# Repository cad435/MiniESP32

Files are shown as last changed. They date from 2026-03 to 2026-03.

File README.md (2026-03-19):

# MiniESP32
A very small dev-board for the original ESP32 (XTENSA Dual-Core) with USB-C PD support.

---

## About
Since the ESP32-C3 was released I enjoyed the use of those ultra-small dev-boards.
Sadly there were no such dev-boards for the "original" ESP32 (XTENSA Dual-Core), so I created my own.

The board measures just **25x31mm** — only slightly bigger than the ESP32-WROOM module itself (19x26mm).

## Features
- **USB-C** connector
- **USB-PD** support via **CH224Q** PD controller
- **Switchable V+ output** — USB-PD voltage can be enabled/disabled via GPIO18
- All usable GPIOs broken out on 2.54mm headers
- 2x I2C, 2x UART, Touch, DAC, ADC
- Onboard LED on GPIO02, Boot button on GPIO00

## USB Power Delivery (CH224Q)
The V2.2 PD revision includes a **CH224Q** USB-PD sink controller.

- **Default output: 9V** — the CH224Q negotiates 9V on power-up
- The voltage can be changed to **5V** via software using the [CH224Q Arduino Library](https://github.com/cad435/CH224Q_Arduino)
- **V+ is switched** — GPIO18 controls a MOSFET that connects/disconnects the negotiated PD voltage to the V+ output pin. This allows you to turn the power output on and off programmatically
- **I2C connection** — the CH224Q is connected to I2C1 on GPIO21 (SDA) and GPIO22 (SCL)

## Pinout

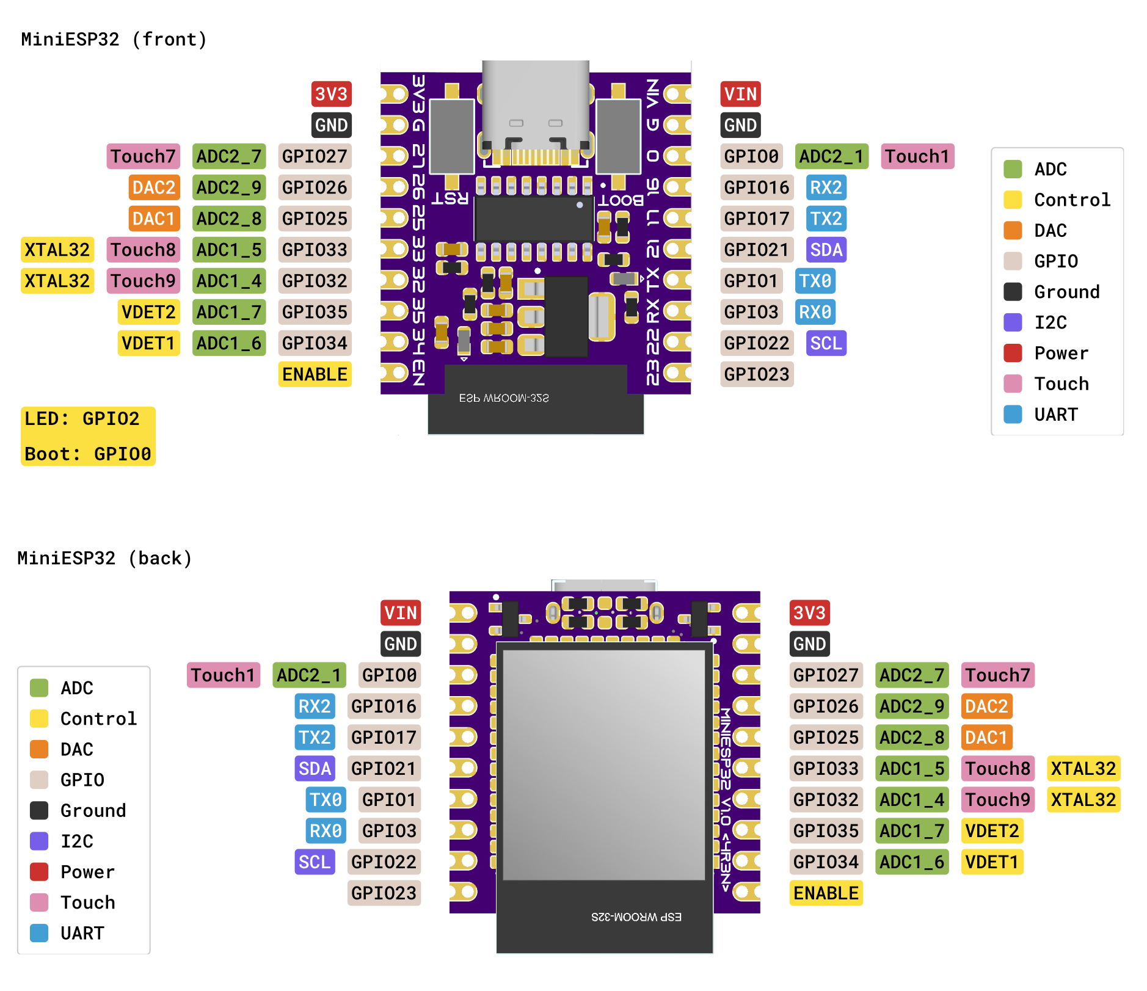
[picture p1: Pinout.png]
Pinout


## Manufacturing

Gerber and provided .xlsx files can be used to directly upload to JLCPCB (*.xlsx files for assembly service).

## Files
| File | Description |
|---|---|
| `MiniESP32_Gerber.zip` | Gerber files (panelized, ready for JLCPCB) |
| `MiniESP32_V2.2 PD-Schematic.PDF` | Schematic |
| `BOM-MiniESP32(V2.2 PD).pdf` | Bill of Materials |
| `MiniESP32_V2.2 PD_Assembly.PDF` | Assembly drawing |
| `MiniESP32_V2.2 PD_BoardSpec.PDF` | Board specifications |
| `JLC_PCBA_BOM-MiniESP32(V2.2 PD).xlsx` | BOM for JLCPCB assembly |
| `JLC_PCBA_CPL-MiniESP32(V2.2 PD).xlsx` | Component placement for JLCPCB assembly |
| `MiniESP32.step` | 3D model (STEP) |

## Photo

27b760d5-4e83-46a3-9fcc-3738d6150797

Note: the patched diode is now fixed and uploaded!

## License
Licensed under the [Open Source Hardware Association License](https://www.oshwa.org/definition/)

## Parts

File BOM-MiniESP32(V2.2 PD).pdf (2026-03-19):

Comment | Description | Value | Designator | Footprint | Quantity
CH224Q | USB PD and Other Fast Charging Protocol Sink Controller | | A2 | DFN40P200X75_HS-11N | 1
1uF/50V | Capacitor | 1uF/25V, 1uF/50V | C1, C2, C3, C5 | C0603 | 4
100nF | Capacitor | 100nF | C7, C8, C22, C24, C25 | C0402 | 5
10uF/50V | Capacitor | 10uF/50V | C10, C11 | C0805 | 2
10uF | Capacitor | 10uF | C23, C26, C27 | C0402 | 3
C2286 | SMD LED | | D1, D2 | 0603_LED | 2
C2290 | SMD LED | | D3 | 0603_LED | 1
15V/BZT52C15S | 15V/BZT52C15S | | D4 | SOD-323 | 1
B5819W SL | Diode | | D5 | SOD-123 | 1
ME3116 | 1A up to 40V Input Step-Down DC/DC Regulator | | IC1 | SOT23-6 | 1
C720477 | Tactile Switch | | J2, J3 | TS-1088-AR02016 | 2
USB 3.1 C Receptacle | USB 3.1 Type C Receptacle Horizontal THR WR-COM | | J4 | C165948 | 1
VLS252012HBX-100M-1 | VLS252012HBX-100M-1 | 10uH | L1 | 2.5x2mm | 1
ESP32S_Module | Esp-32S | | M1 | ESP32S | 1
WSD30L68DN33 | 20V P-Channel MOSFET | | Q1 | SON3x3 | 1
AO3400A | N-MOSFET SI2318CDS-T1-GE3 | | Q2, Q6, Q7 | SOT95P240X1.10-3N_SOT-23 | 3
1.5k | Resistor | 1.5k | R1, R2, R12 | 0402 | 3
6.8k | Resistor | 6.8k | R7 | R0603 | 1
100k | Resistor | 100k | R9, R16 | 0402 | 2
1M | Resistor | 1M | R10 | 0402 | 1
33k | Resistor | 33k | R11 | 0402 | 1
10k | Resistor | 10k | R13, R14, R17, R18, R25, R26, R27, R28 | 0402 | 8
1k | Resistor | 1k | R20 | 0402 | 1
CH340K | | | U1 | ESSOP100P600X180_E P-11N wo vias | 1

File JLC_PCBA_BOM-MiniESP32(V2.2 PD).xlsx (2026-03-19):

Comment | Description | Value | Designator | Footprint | Quantity | JLCPCB Part #
CH224Q | USB PD and Other Fast Charging Protocol Sink Controller |  | A2 | DFN40P200X75_HS-11N | 1 | C46061833
1uF/50V | Capacitor | 1uF/50V | C1 | C0603 | 1 | C15849
1uF/50V | Capacitor | 1uF/50V | C2 | C0603 | 1 | C15849
1uF/50V | Capacitor | 1uF/50V | C3 | C0603 | 1 | C15849
1uF/50V | Capacitor | 1uF/50V | C5 | C0603 | 1 | C15849
100nF | Capacitor | 100nF | C7, C8, C22, C24, C25 | C0402 | 5 | C307331
10uF/50V | Capacitor | 10uF/50V | C10, C11 | C0805 | 2 | C440198
10uF | Capacitor | 10uF | C23, C26, C27 | C0402 | 3 | C15525
C2286 | SMD LED |  | D1, D2 | 0603_LED | 2 | C2286
C2290 | SMD LED |  | D3 | 0603_LED | 1 | C2290
15V/BZT52C15S | Zener |  | D4 | SOD-323 | 1 | C19077448
ME3116 | 1A up to 40V Input Step-Down DC/DC Regulator |  | IC1 | SOT23-6 | 1 | C97643
C720477 | Tactile Switch |  | J2, J3 | TS-1088-AR02016 | 2 | C720477
USB 3.1 C Receptacle | USB 3.1 Type C Receptacle Horizontal THR WR-COM |  | J4 | C165948 | 1 | C165948
VLS252012HBX-100M-1 | VLS252012HBX-100M-1 | 10uH | L1 | 2.5x2mm | 1 | C88532
ESP32-WROOM | ESP32-WROOM | ESP32-WROOM | M1 | ESP32S | 1
WSD30L68DN33 | 20V P-Channel MOSFET |  | Q1 | SON3x3 | 1 | C5242075
AO3400A | N-MOSFET SI2318CDS-T1-GE3 |  | Q2, Q6, Q7 | SOT95P240X1.10-3N_SOT-23 | 3 | C20917
1.5k | Resistor | 1.5k | R1, R2, R12 | 0402 | 3 | C25867
6.8k | Resistor | 6.8k | R7 | R0603 | 1 | C23212
100k | Resistor | 100k | R9, R16 | 0402 | 2 | C25741
1M | Resistor | 1M | R10 | 0402 | 1 | C26083
33k | Resistor | 33k | R11 | 0402 | 1 | C25779
10k | Resistor | 10k | R13, R14, R17, R18, R25, R26, R27, R28 | 0402 | 8 | C25744
CH340K |  |  | U1 | ESSOP100P600X180_EP-11N wo vias | 1 | C18208922
B5819W SL | Diode |  | D5 | SOD-123 | 1

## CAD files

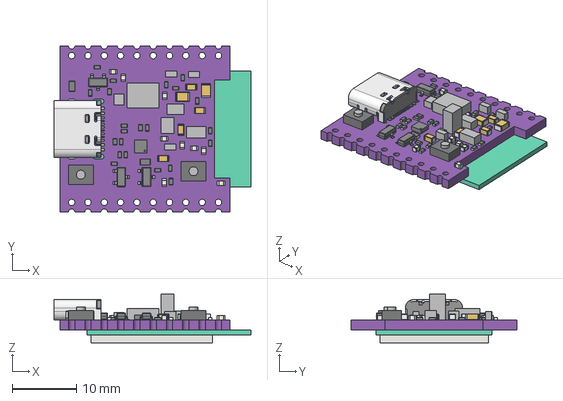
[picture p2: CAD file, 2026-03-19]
MiniESP32.step
30.7 x 25.9 x 7.56 mm

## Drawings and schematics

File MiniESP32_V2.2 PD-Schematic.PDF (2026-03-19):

10k | R4
10k | R5

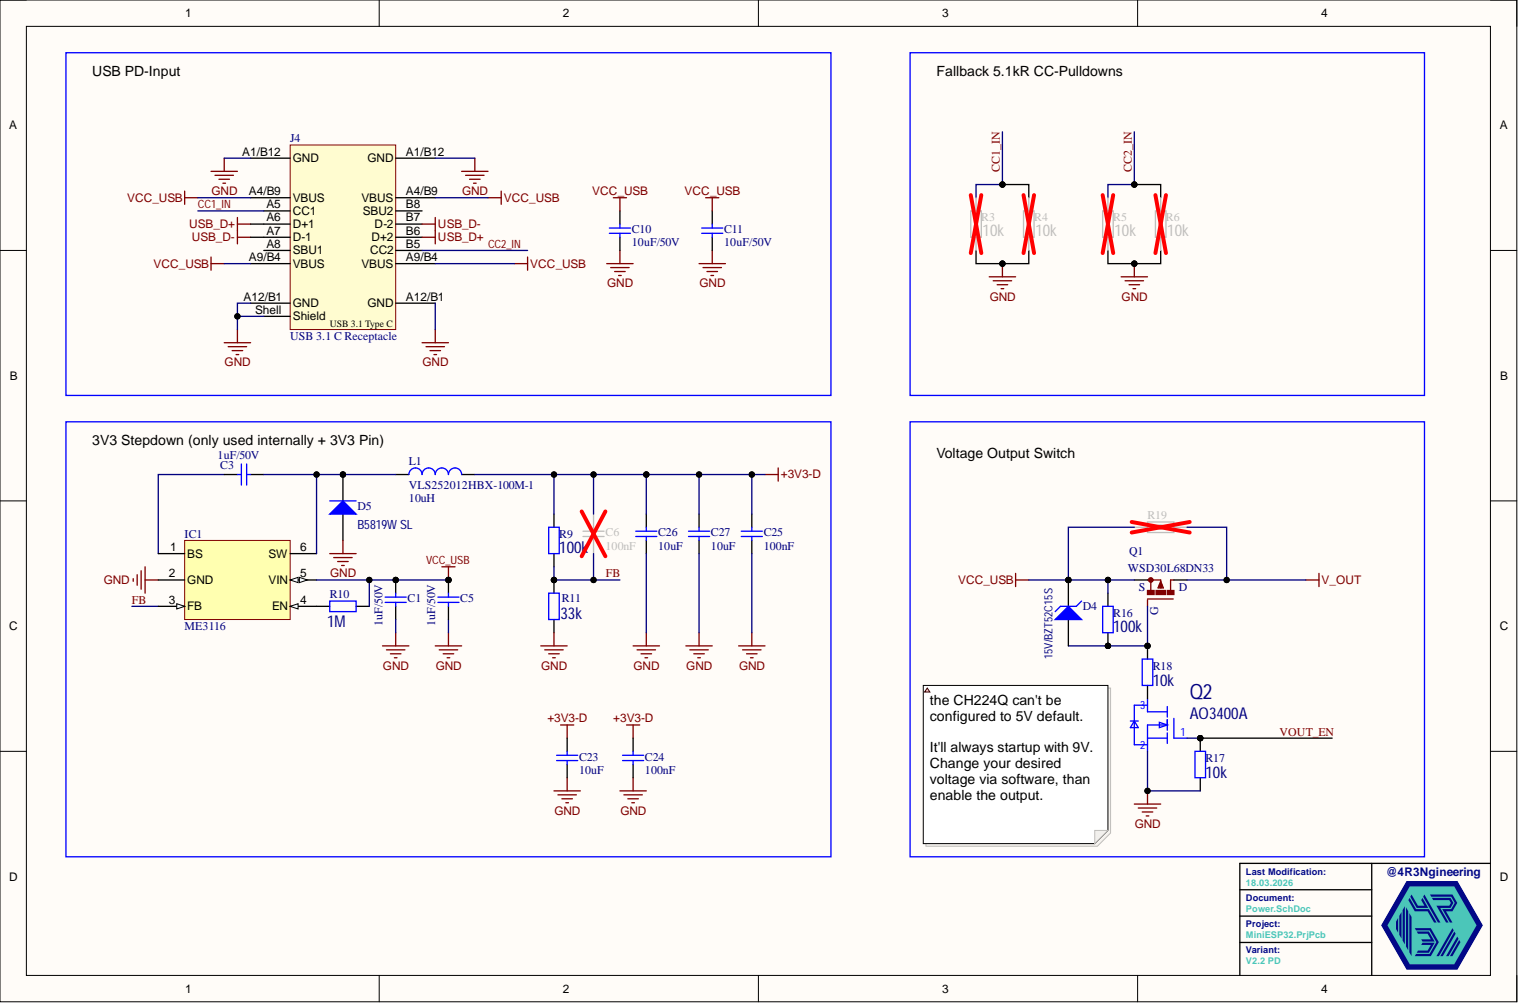
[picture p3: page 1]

3V3 Stepdown (only used internally + 3V3 Pin)

It'll always startup with 9V.
Change your desired
voltage via software, than
enable the output.

# 5 10 IO26 11 IO27 12 IO14 13 IO12 14

# 5 23 IO2 24 IO0 25 IO4 26 IO16 27 IO17 28 IO5 29 IO18 30 IO19 31

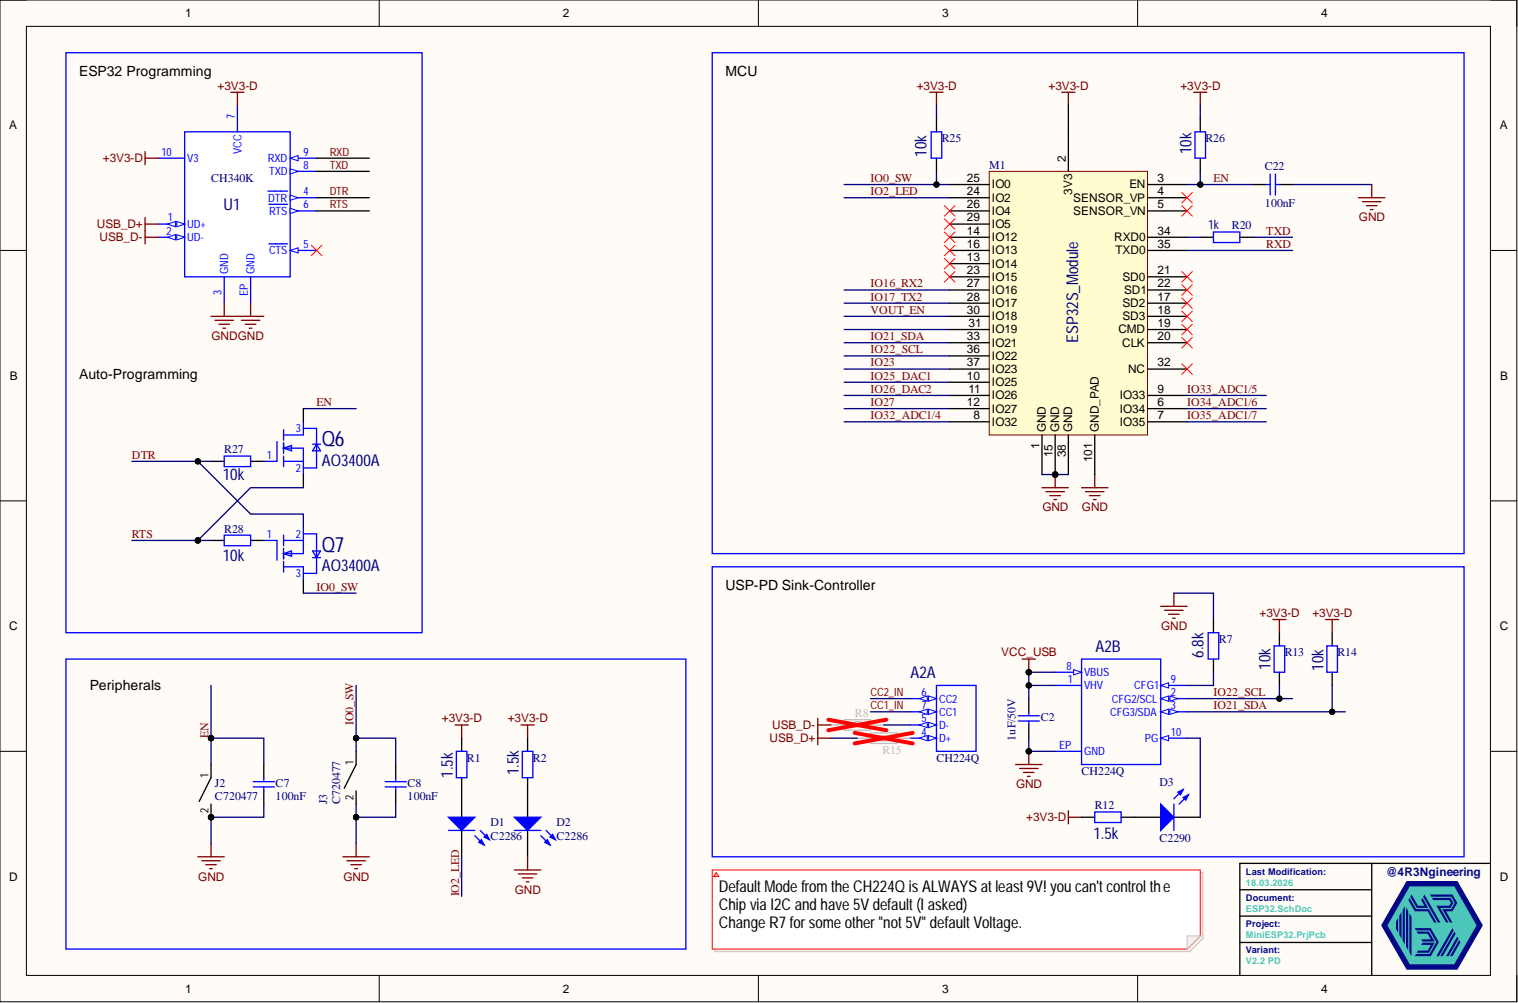
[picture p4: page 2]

from
I2C and have 5V default (I asked)
for some other "not 5V" default Voltage.

the CH224Q is ALWAYS at least 9V! you can't control

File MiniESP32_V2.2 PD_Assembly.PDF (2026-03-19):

A

B

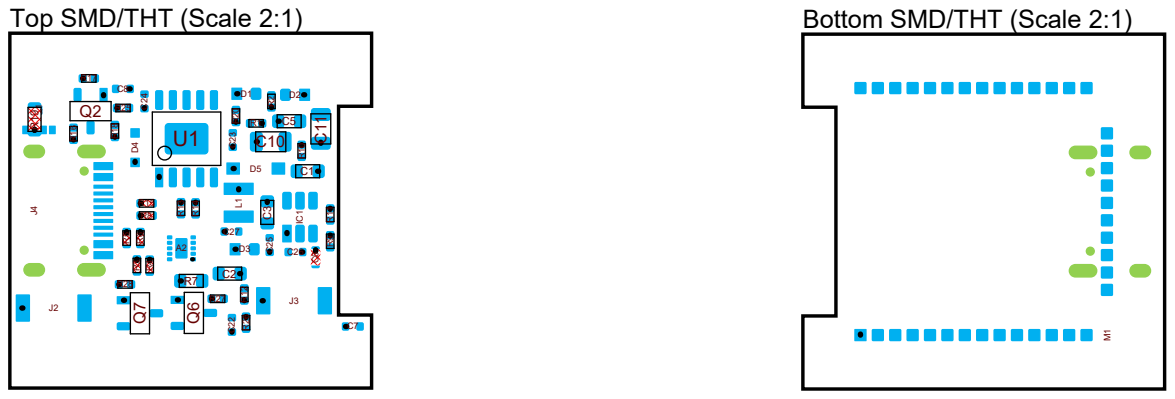
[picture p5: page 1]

Top SMD/THT (Scale 2:1)

Bottom SMD/THT (Scale 2:1)

1 | 1

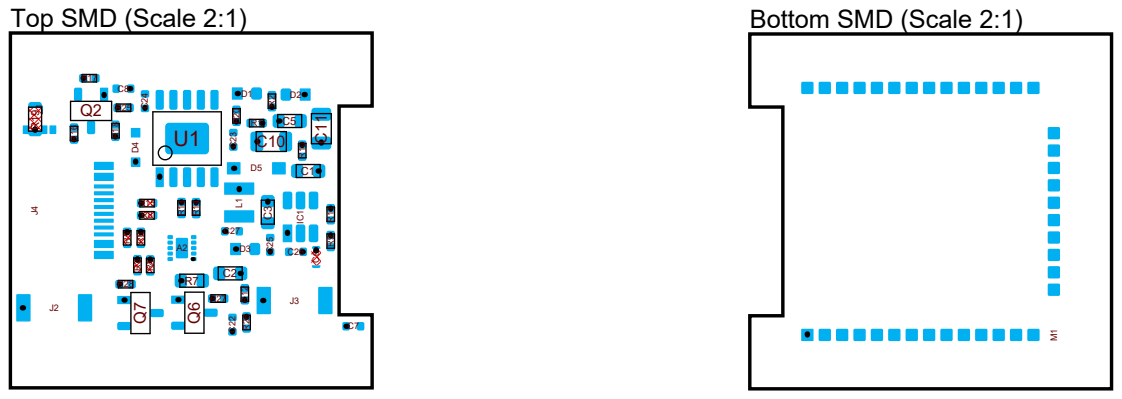
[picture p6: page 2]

1 | 1

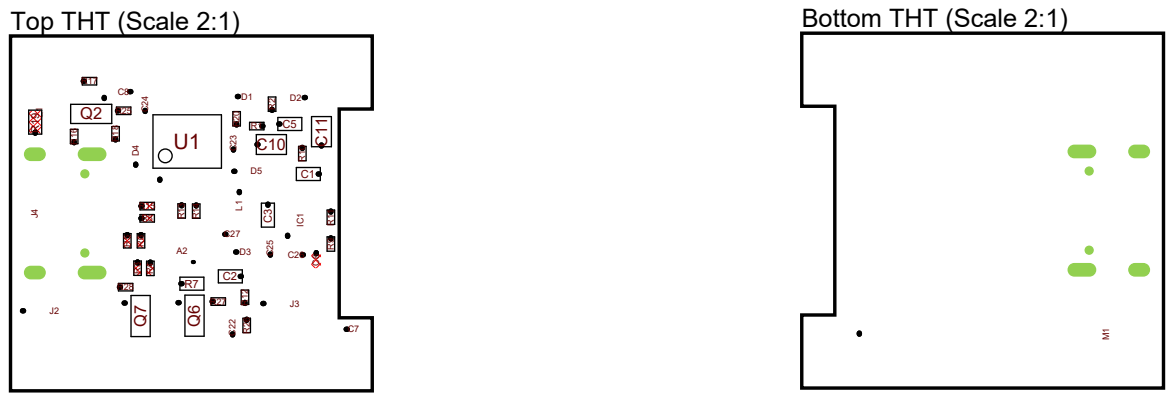
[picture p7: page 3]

1 | 1

# Realistic View

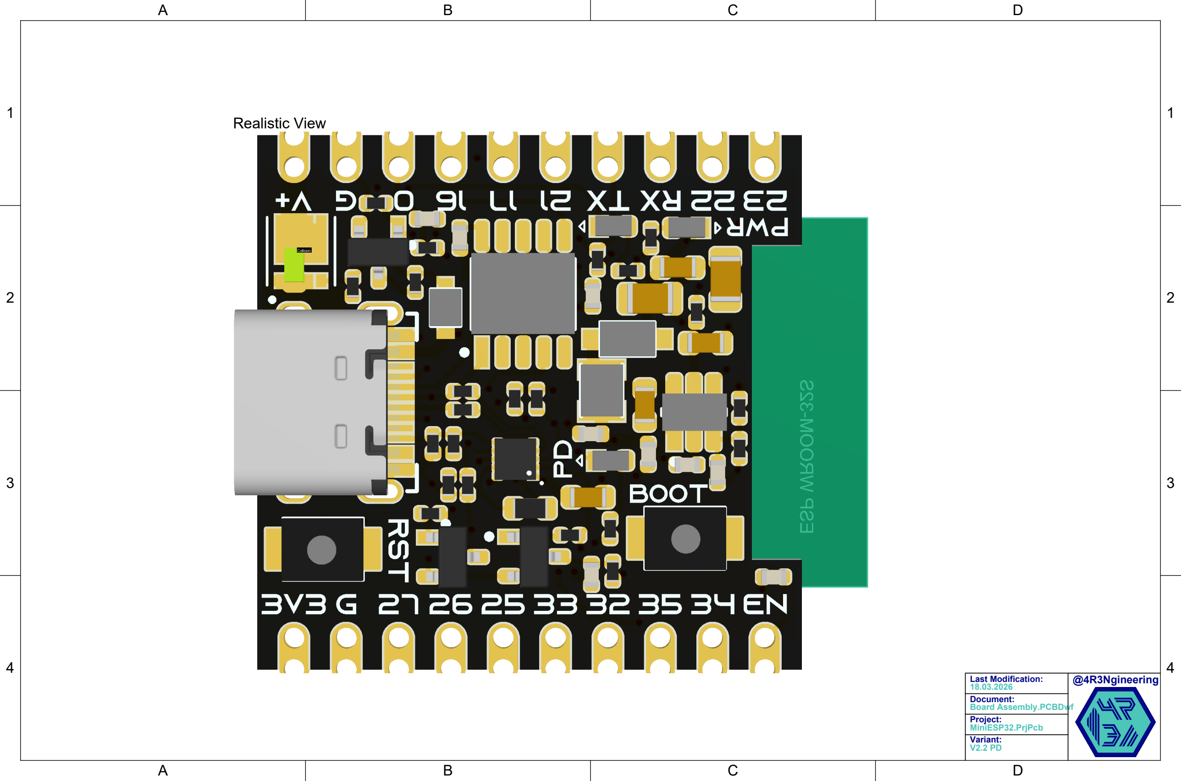
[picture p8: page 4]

2 | 2
3 | 3
4 | 4
Last Modification: | @4R3Ngineering
18.03.2026
Document:
Board Assembly.PCBDwf

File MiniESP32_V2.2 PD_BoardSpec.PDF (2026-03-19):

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
PCB Name
Size
Attached Layerstack mandatory Layers
Thickness
Material
Copper-Thickness top/bottom Copper-Thickness inner layers Surface
Solder mask
Peelable mask
Scoring
UL required
Outline/Shape
Chamfer
Electrical Test
Impedance
IPC/Perfag
internal millings
Silkscreen Top
Silkscreen Bottom
Pressfit

MiniESP32
Xmm x Xmm (see drawing)
no4

1.6mm
FR4 / Epoxy
35µm
17.5µm
chemical Ni/Au
double-sided (purple)
no
no
no
milling
no
yes
no
Class 2
yes
yes
yes
no
Last Modification: | @4R3Ngineering
18.03.2026
Document:
Board Specification.PCBDwf
Project:
MiniESP32.PrjPcb
Variant:
V2.2 PD

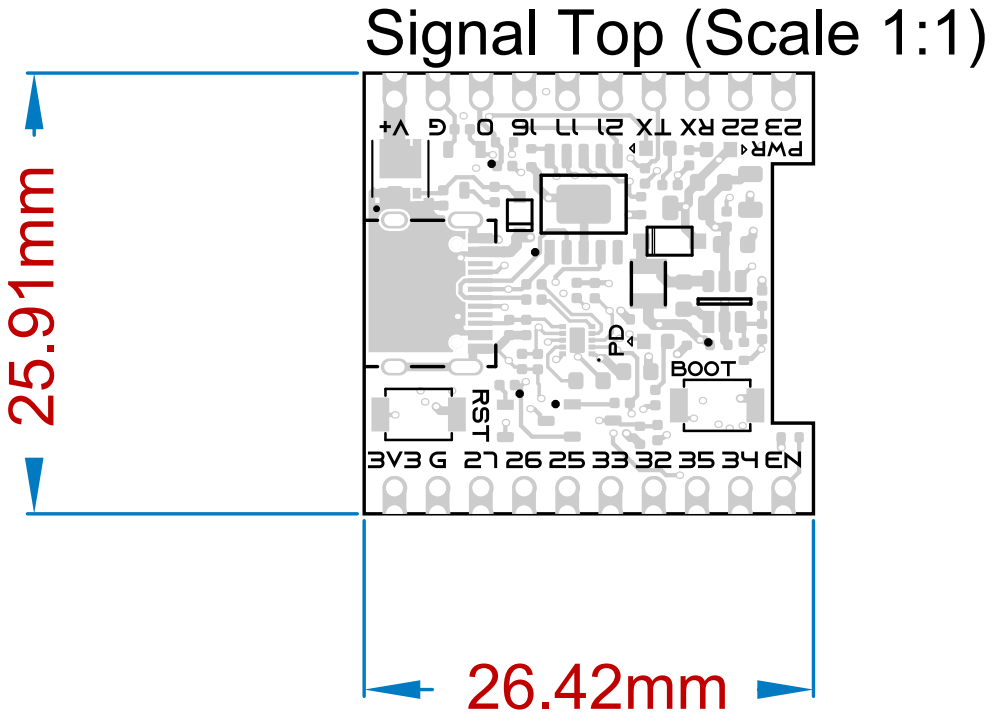
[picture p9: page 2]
Last Modification:; @4R3Ngineering; 18.03.2026 Document: Board Specification.PCBDwf

Signal Top (Scale 1:1)

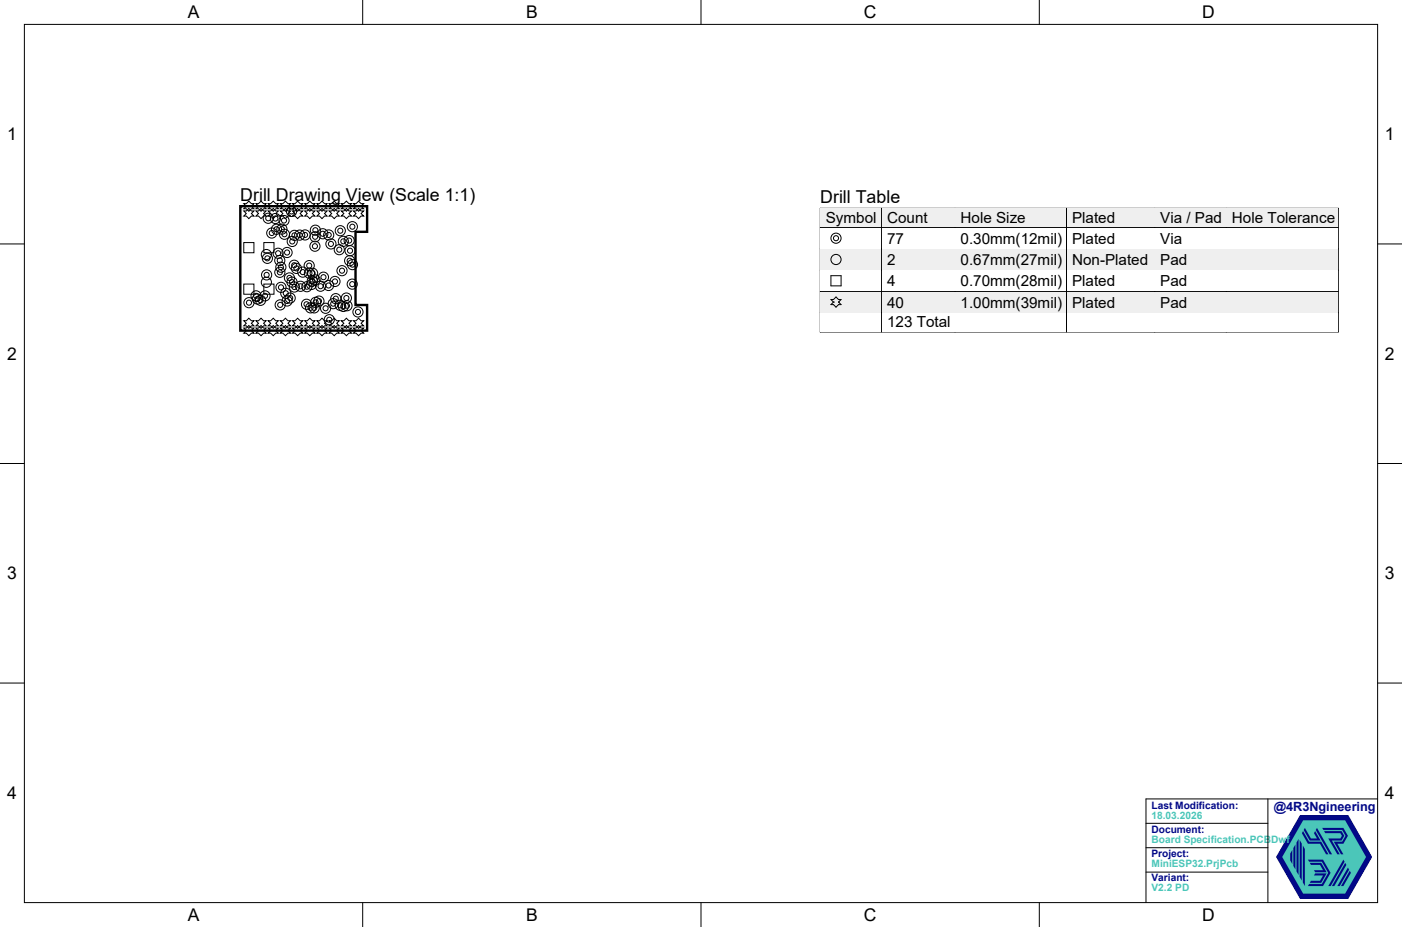
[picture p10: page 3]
Drill Table; Last Modification:; @4R3Ngineering; 18.03.2026 Document: Board Specification.PCBDwf

Drill Drawing View (Scale 1:1)

Symbol | Count | Hole Size | Plated | Via / Pad | Hole Tolerance

77 | 0.30mm(12mil) | Plated | Via
2 | 0.67mm(27mil) | Non-Plated | Pad
4 | 0.70mm(28mil) | Plated | Pad
40 | 1.00mm(39mil) | Plated | Pad
123 Total
